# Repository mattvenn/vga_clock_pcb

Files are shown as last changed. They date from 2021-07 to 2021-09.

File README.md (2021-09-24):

Matt Venn's ASIC VGA Clock
==========================

* World's first [certified open source hardware](https://certification.oshwa.org/es000023.html) down to the GDS?
* The ASIC was part of the Google sponsored MPW1
* The ASIC is still in fabrication by Skywater, we expect silicon in September 2021.
* For more details about the implementation, see [VGA ASIC Clock](https://www.zerotoasiccourse.com/post/vga_clock/). 
* RTL: https://github.com/mattvenn/vga-clock
* Application details: https://efabless.com/projects/14

# PCB

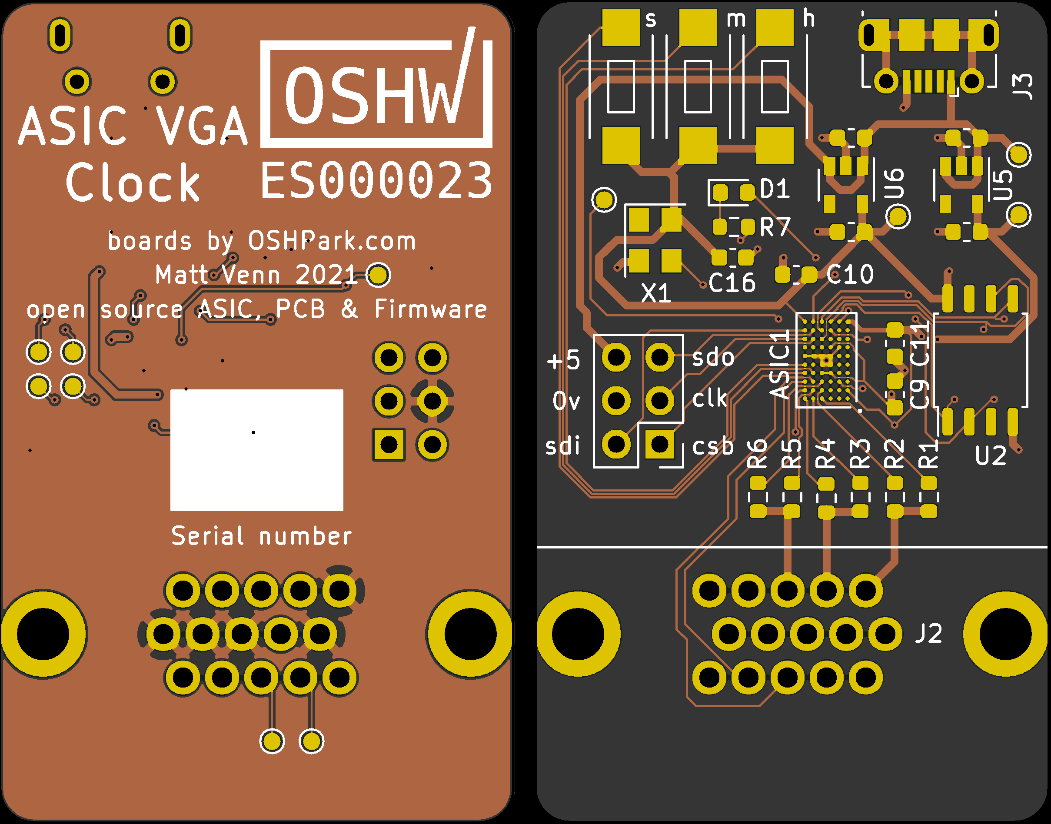
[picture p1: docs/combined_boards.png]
boards


This PCB provides all the necessary components to make a functional clock:

 * Pads for mounting the ASIC
 * Decoupling
 * Voltage regulators for core (1.8) and IO (3.3)
 * Crystal oscillator
 * SOIC-8 footprint for dual SPI flash for the configuration firmware
 * 2x6 1.27mm header with housekeeping SPI, UART and 5V - the minimum connection needed for power and debug
 * [PDF Schematic](rev0.1/carrier.pdf)

# Setup

## Firmware

Needs to active project 2. See https://github.com/mattvenn/caravel-mph/blob/release/verilog/dv/caravel/user_proj_example/vga-clock/vga_clock.c for the simulation test.
Will need PLL setup to work on the ASIC.

## Flashing

For flashing, see https://github.com/efabless/ravenna/blob/master/firmware/blink/Makefile as a starting point. ravenna_hkspi.py may need some tweaks to work with Caravel.

The [SPI interface can be used to put the ASIC into 'passthrough' mode](https://caravel-harness.readthedocs.io/en/latest/housekeeping-spi.html#housekeeping-spi-command-words). Then the FLASH can be programmed through this same SPI interface.

See the schematic for the pinout of the SPI interface on the board.

## PLL config

Needs 31.5MHz for VGA signal. As precise as possible for good timekeeping.
Input oscillator is 9MHz.

Using https://github.com/kbeckmann/caravel-pll-calculator

    matt-desktop:2003 [main]: ./caravel_pll.py generate --clkout 31.5 --clkin 9
    PLL Parameters:

    clkin:    9.00 MHz
    clkout:   31.50 MHz
    clkout90: 31.50 MHz

    PLL Feedback Divider: 14
    PLL Output Divider 1: 4
    PLL Output Divider 2: 4

    Register 0x11: 0x24
    Register 0x12: 0x0e

## Pinning

See the instantiation into the user project area here: https://github.com/mattvenn/multi-project-harness/blob/separate-macro/user_project_wrapper.v#L190
See the design repository here: https://github.com/mattvenn/vga-clock/tree/db029c38607c8d27f54b48bd8fd423cae3c4ed3d

    vga_clock proj_2 (
        .clk(proj2_clk),
        .reset_n(proj2_reset),
        .adj_hrs(proj2_io_in[8]),
        .adj_min(proj2_io_in[9]),
        .adj_sec(proj2_io_in[10]),
        .hsync(proj2_io_out[11]),
        .vsync(proj2_io_out[12]),
        .rrggbb(proj2_io_out[18:13])
        );

* rrggbb is mapped to R1, R2, G1, G2, B1, B2
* 500R used for R1, G1, B1
* 1k used for R2, G2, B2

## Power

### User project

* Power is provided to the clock design only by VCCD1 and VSSD1.
* Tim Edwards suggests:
    * keeping VCCD2 and VCCD1, VSSD2 and VSSD1 tied together just to make sure there are no floating power supplies.  
    * connect VDDA1 and VDDA2 to VDDIO, and VSSA1 and VSSA2 to VSSIO to make sure they're not floating.  
For reference, the power ring around the user project area has 4 buses. From outside to inside:  VSSA2, VDDA2, VSSA1, VDDA1, VSSD2, VCCD2, VSSD1, VCCD1.
    * VSSA2 user area 2 ground
    * VDDA2 3.3V user area 2 psu
    * VSSA1 user area 1 ground
    * VDDA1 3.3V user area 1 psu
    * VSSD2 user area 2 digital ground
    * VCCD2 1.8V user area 2 digital psu
    * VSSD1 user area 1 digital ground
    * VCCD1 1.8V user area 1 digital psu

### Management

* VDDIO/VSSIO   power and ground for IO (up to 5v). I'm connecting to 3.3v
* VDDA/VSSA     3.3v PSU for management area
* VCCD/VSSD     1.8v PSU for management area

# BOM

All available from digikey as of 13/7/21

* regulators
    * 1.8v MCP1824T-1802E/OT
    * 3.3v MIC5504-3.3YM5-TR
* flash: W25Q32JVSSIQ-TR
* oscillator: SIT8008AI-23-33S-9.000000 
* VGA connector: L77HDE15SD1CH4F
* USB connector: 1050170001
* buttons: PTS636 SM25J SMTR LFS

# Errata

## v0.1

* Initial footprint for ASIC was flipped. 
* All other components were tested and worked as expected.

## v0.2

* TBD

# Resources

* PCB forked from https://github.com/samlittlewood/caravel_carrier
* Caravel datasheet: https://caravel-harness.readthedocs.io/en/latest
* Logo created at: http://oshwmark.capablerobot.com/
* PCBs sponsored by https://OSHPark.com

# License

* The PCB is licensed under the [MIT License](LICENSE)
* The ASIC is licensed under the [Apache2 License](https://github.com/mattvenn/vga-clock/blob/master/LICENSE-2.0.txt)
* The documentation is licensed under the [CC0 License](CC0_license)

# Open Source Hardware

This board is an OSHWA approved design: [ES000023](https://certification.oshwa.org/es000023.html)

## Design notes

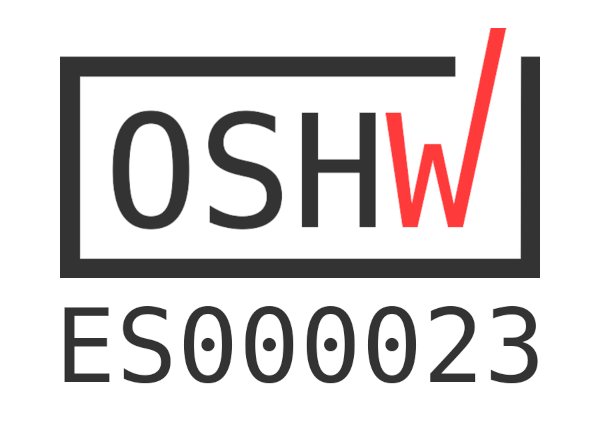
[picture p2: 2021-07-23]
docs/OSHW_mark_ES000023.png

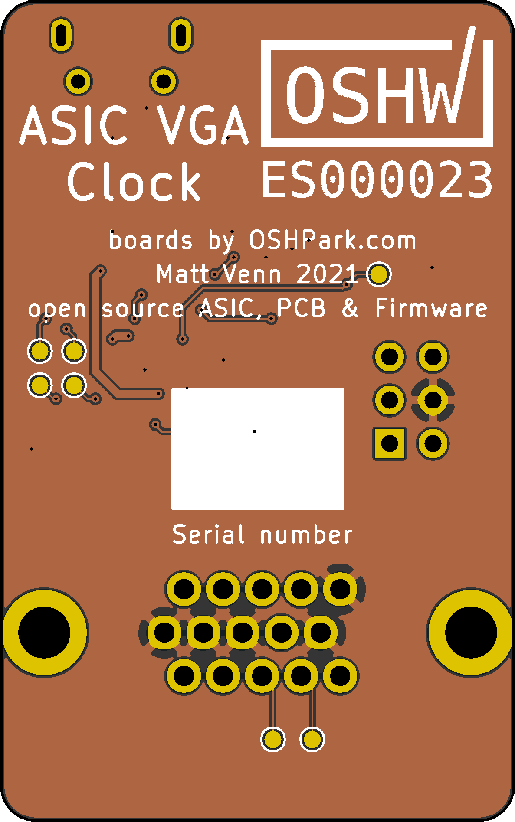
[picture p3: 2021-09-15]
docs/back.png

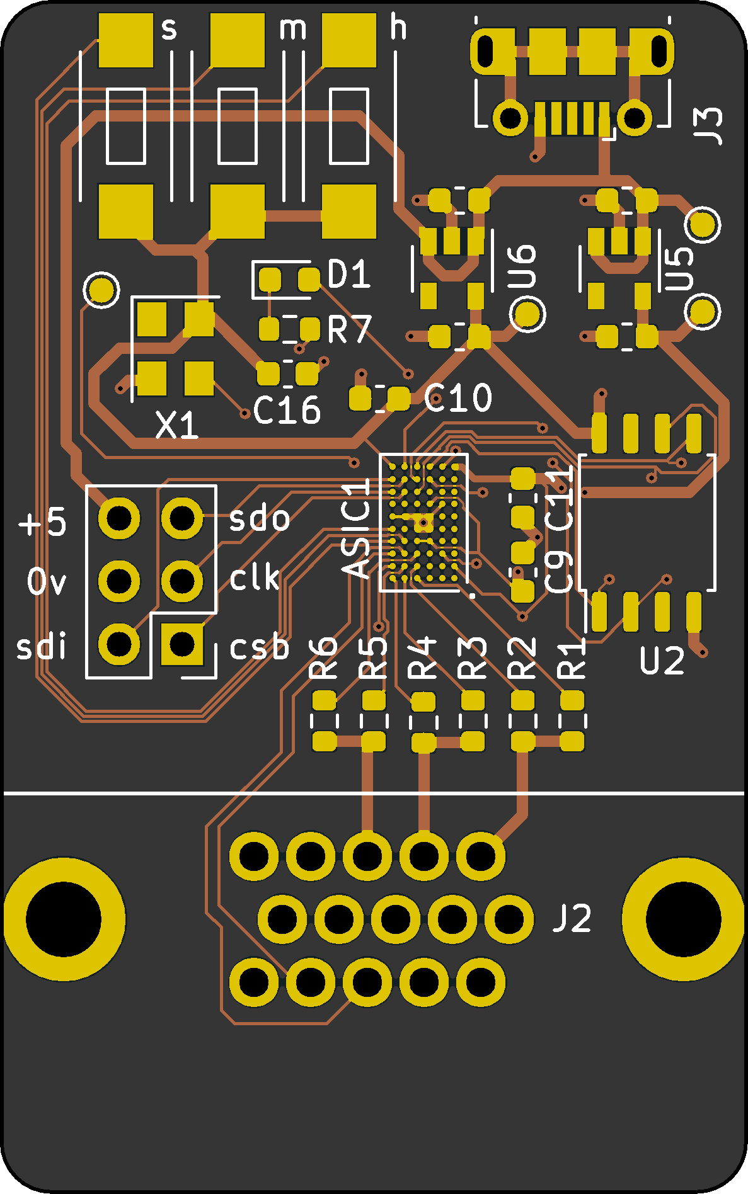
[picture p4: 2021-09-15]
docs/front.png

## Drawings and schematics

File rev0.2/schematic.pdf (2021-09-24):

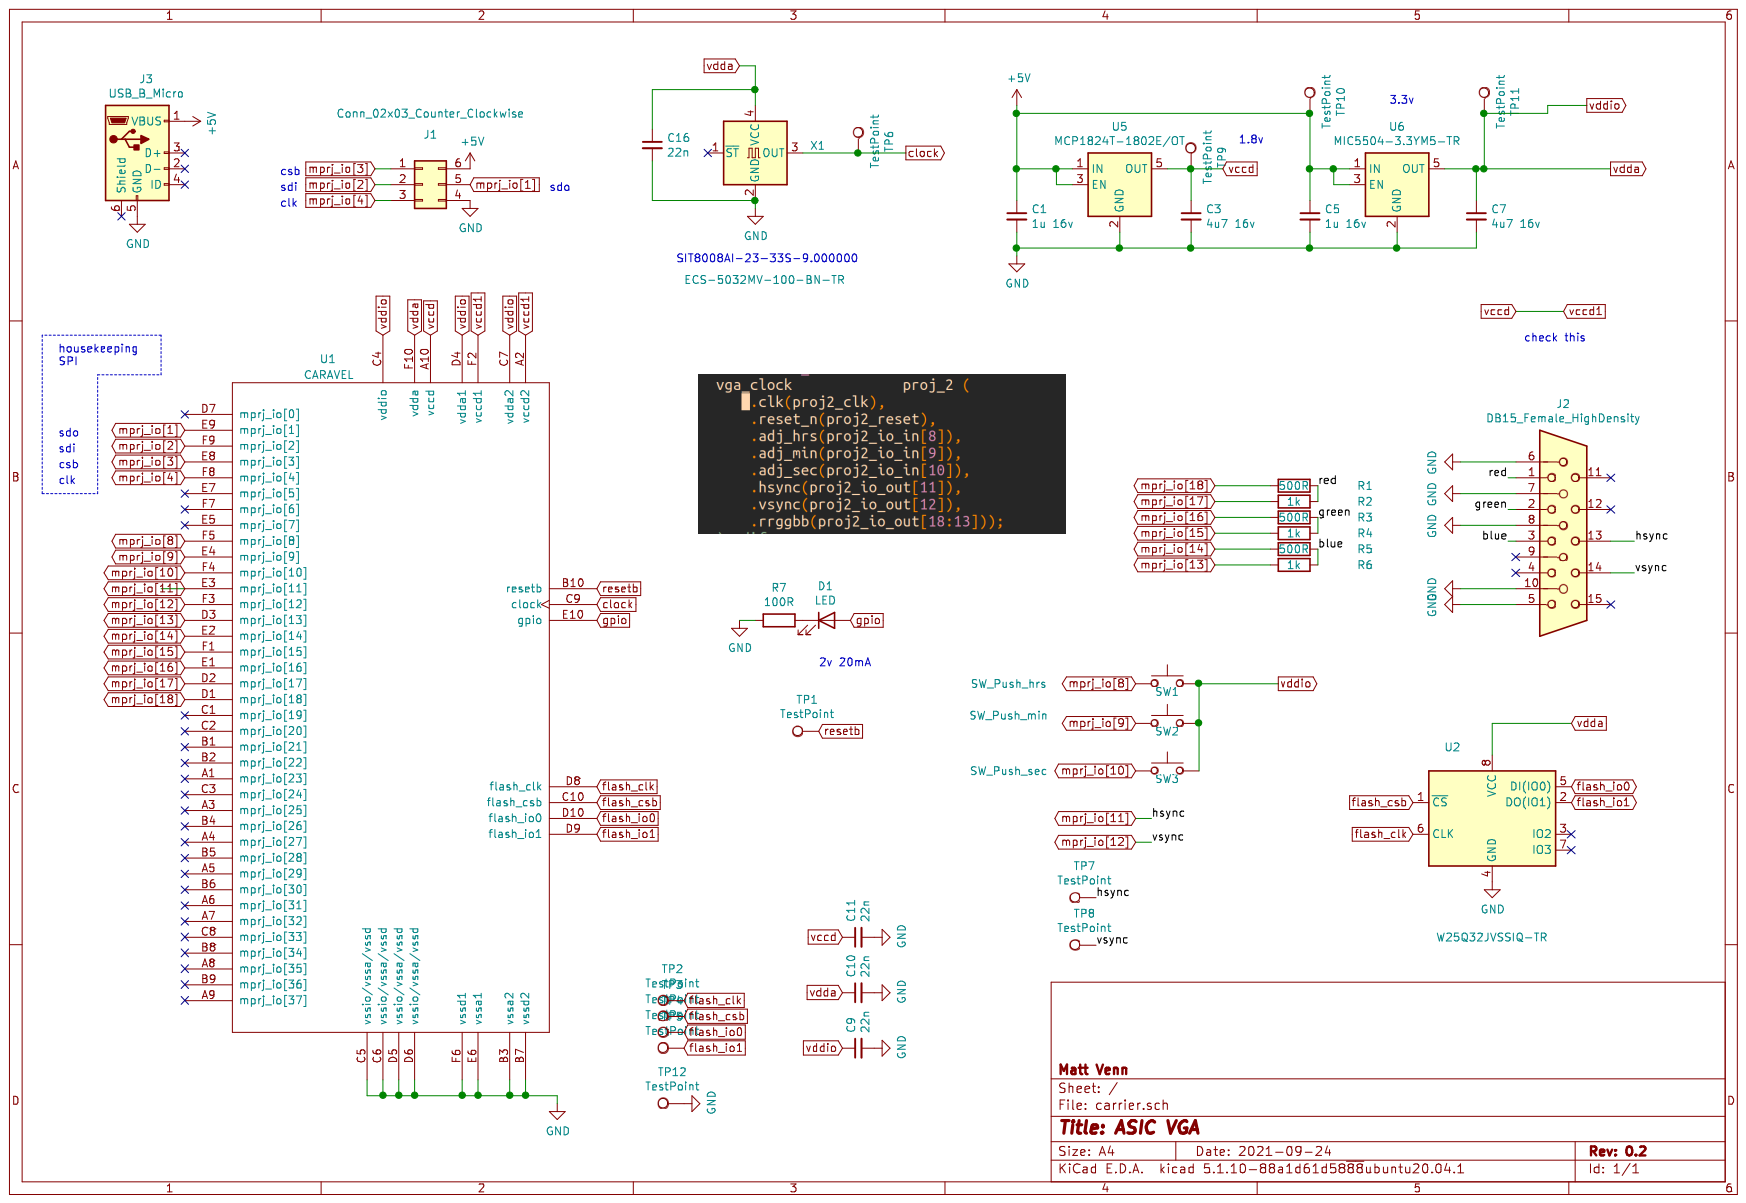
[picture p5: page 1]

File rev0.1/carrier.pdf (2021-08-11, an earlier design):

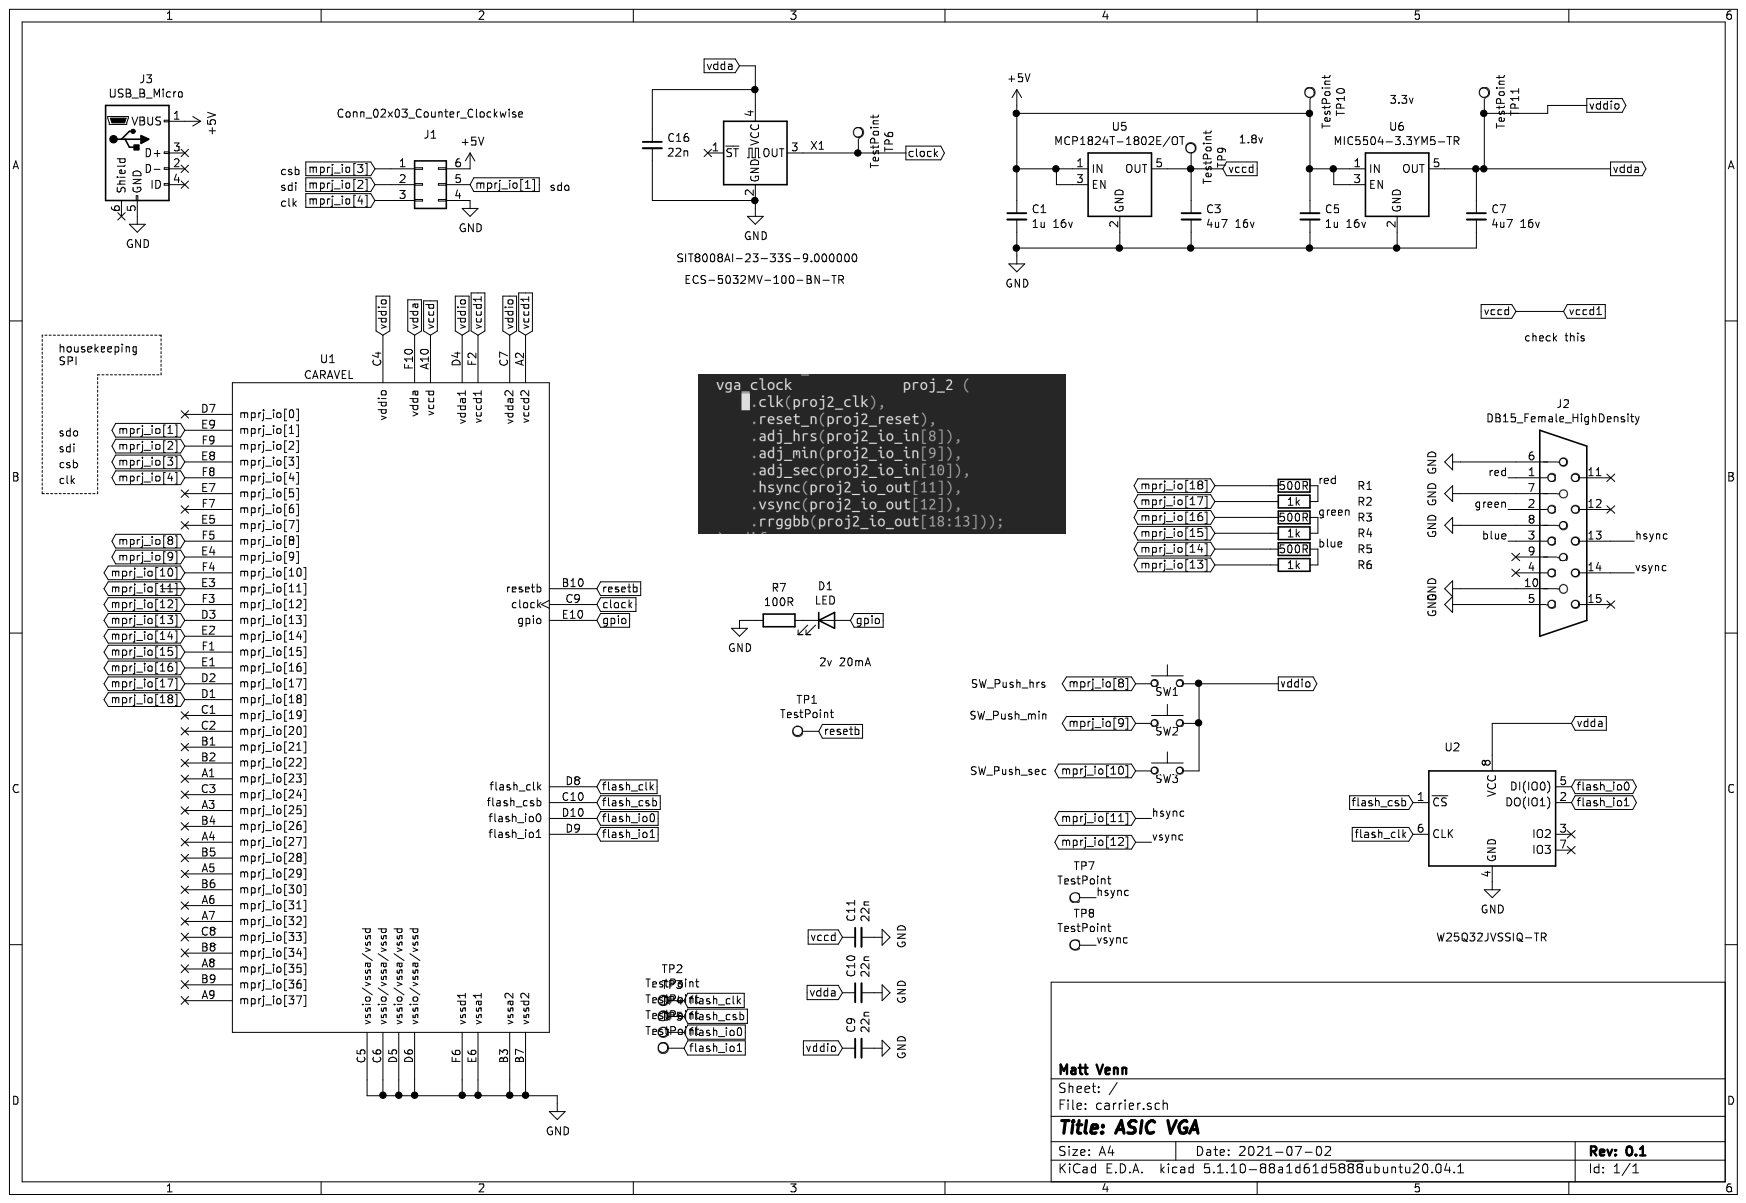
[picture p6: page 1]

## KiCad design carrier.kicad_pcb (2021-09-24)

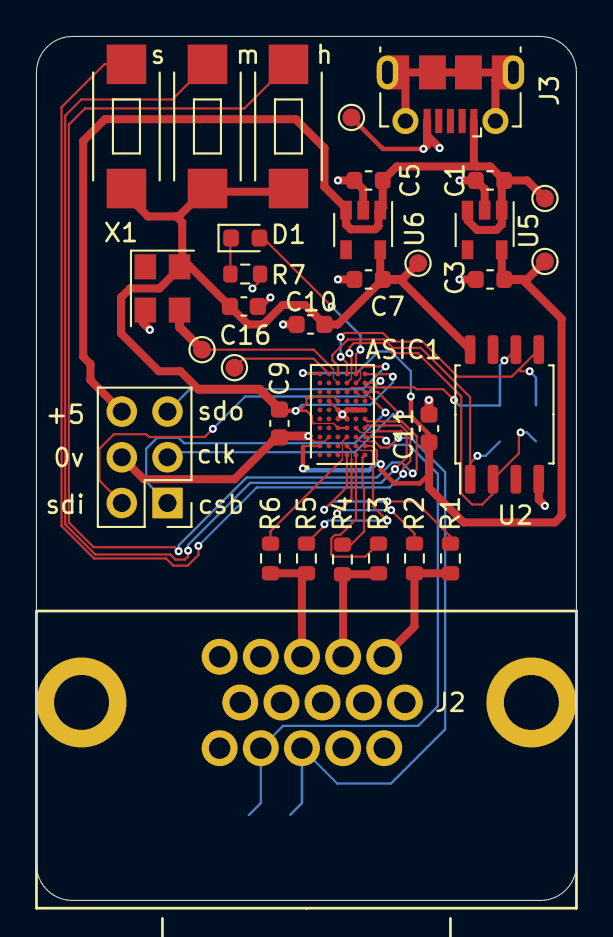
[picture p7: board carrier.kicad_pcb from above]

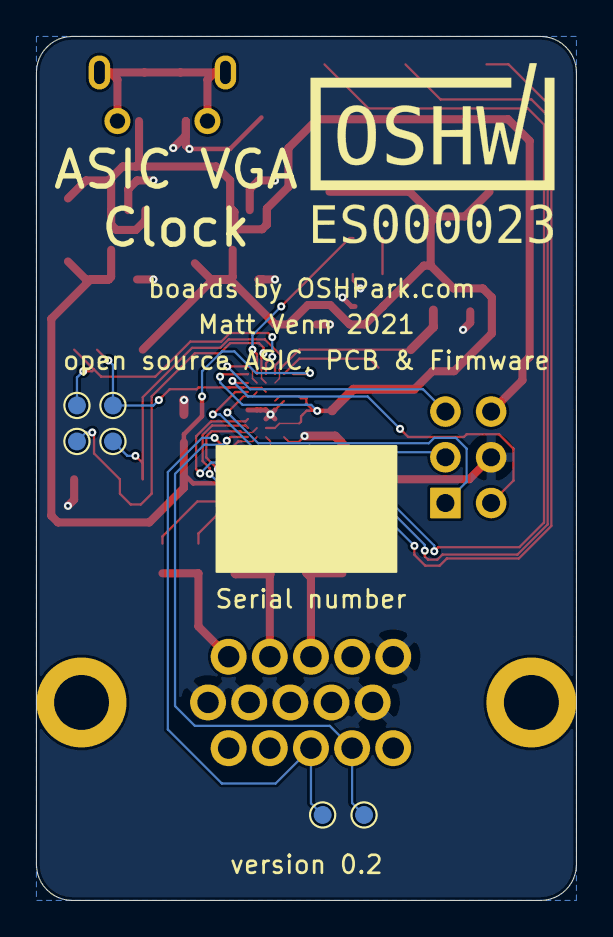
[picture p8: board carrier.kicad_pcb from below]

Board: 2 copper layers, 30.0 x 48.0 mm, 39 parts (6 on the bottom side), 30 nets.

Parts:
ASIC1: CARAVEL; WLCSP-60_P0.5mm
C1, C5: 1u 16v; C_0603_1608Metric
C3, C7: 4u7 16v; C_0603_1608Metric
C9, C10, C11, C16: 22n; C_0603_1608Metric
D1: LED; LED_0603_1608Metric
J1: Conn_02x03_Counter_Clockwise; PinHeader_2x03_P2.54mm_Vertical
J2: DB15_Female_HighDensity; db15
J3: USB_B_Micro; USB_Micro-B_Molex-105017-0001
R1, R3, R5: 500R; R_0603_1608Metric
R2, R4, R6: 1k; R_0603_1608Metric
R7: 100R; R_0603_1608Metric
SW1: SW_Push_hrs; pts636
SW2: SW_Push_min; pts636
SW3: SW_Push_sec; pts636
TP1, TP2, TP3, TP4, TP5, TP6, TP7, TP8, TP9, TP10, TP11, TP12: TestPoint; TestPoint_Pad_D1.0mm
U2: W25Q32JVSSIQ-TR; SOIC-8_5.23x5.23mm_P1.27mm
U5: MCP1824T-1802E/OT; SOT-23-5
U6: MIC5504-3.3YM5-TR; SOT-23-5
X1: ECS-5032MV-100-BN-TR; Oscillator_SMD_SeikoEpson_SG8002CE-4Pin_3.2x2.5mm

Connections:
+5V: C1.1, C5.1, J1.6, J3.1, TP10.1, U5.1, U5.3, U6.1, U6.3
/blue: J2.3, R5.1, R6.1
/green: J2.2, R3.1, R4.1
/red: J2.1, R1.1, R2.1
GND: ASIC1.B3, ASIC1.B7, ASIC1.C5, ASIC1.C6, ASIC1.D5, ASIC1.D6, ASIC1.E6, ASIC1.F6, C1.2, C3.2, C5.2, C7.2, C9.2, C10.2, C11.2, C16.2, J1.4, J2.5, J2.6, J2.7, J2.8, J2.10, J3.5, R7.2, TP12.1, U2.4, U5.2, U6.2, X1.2
unnamed: D1.1, R7.1
clock: ASIC1.C9, TP6.1, X1.3
flash_clk: ASIC1.D8, TP2.1, U2.6
flash_csb: ASIC1.C10, TP3.1, U2.1
flash_io0: ASIC1.D10, TP4.1, U2.5
flash_io1: ASIC1.D9, TP5.1, U2.2
gpio: ASIC1.E10, D1.2
mprj_io[1]: ASIC1.E9, J1.5
mprj_io[2]: ASIC1.F9, J1.2
mprj_io[3]: ASIC1.E8, J1.1
mprj_io[4]: ASIC1.F8, J1.3
mprj_io[8]: ASIC1.F5, SW1.1
mprj_io[9]: ASIC1.E4, SW2.1
mprj_io[10]: ASIC1.F4, SW3.1
mprj_io[11]: ASIC1.E3, J2.13, TP7.1
mprj_io[12]: ASIC1.F3, J2.14, TP8.1
mprj_io[13]: ASIC1.D3, R6.2
mprj_io[14]: ASIC1.E2, R5.2
mprj_io[15]: ASIC1.F1, R4.2
mprj_io[16]: ASIC1.E1, R3.2
mprj_io[17]: ASIC1.D2, R2.2
mprj_io[18]: ASIC1.D1, R1.2
resetb: ASIC1.B10, TP1.1
vccd: ASIC1.A2, ASIC1.A10, ASIC1.F2, C3.1, C11.1, TP9.1, U5.5
vdda: ASIC1.C4, ASIC1.C7, ASIC1.D4, ASIC1.F10, C7.1, C9.1, C10.1, C16.1, SW1.2, SW2.2, SW3.2, TP11.1, U2.8, U6.5, X1.4

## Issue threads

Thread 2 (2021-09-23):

ASIC footprint is flipped

mattvenn, 2021-09-23:

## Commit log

2020-11-21 Add kicad files.
    [carrier-B_Cu.gbr, carrier-B_Mask.gbr, carrier-B_Paste.gbr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]
2020-11-23 Tidy up and ground pours.
    [carrier.kicad_pcb, carrier.sch]
2020-11-23 Updated plots.
    [carrier-B_Cu.gbr, carrier-B_Mask.gbr, carrier-B_Paste.gbr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]
2020-11-23 Tidy up regulators.
    [carrier.kicad_pcb]
2020-11-23 Flipped to have regulators at top, makes pin/io number a better match.
    [carrier-B_Cu.gbr, carrier-B_Mask.gbr, carrier-B_Paste.gbr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]
2020-11-23 Tidy up power routing.
    [carrier-B_Cu.gbr, carrier-B_Mask.gbr, carrier-B_Paste.gbr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]
2020-11-23 Tidy up oscillator.
    [carrier-B_Cu.gbr, carrier-B_Mask.gbr, carrier-B_Paste.gbr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]
2020-11-23 Solder mask clearance.
    [carrier-B_Cu.gbr, carrier-B_Mask.gbr, carrier-B_Paste.gbr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]
2020-11-24 Use 1.27mm header.
    [carrier-B_Cu.gbr, carrier-B_Mask.gbr, carrier-B_Paste.gbr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]
2020-11-27 Clean up clearances.
    [carrier-B_Cu.gbr, carrier-B_Mask.gbr, carrier-B_Paste.gbr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]
2020-12-18 Use 5mil for inner layers.
    [carrier.kicad_pcb]
2020-12-18 Correct directions on global labels.
    [carrier.kicad_pcb, carrier.sch]
2020-12-20 Update gerbers & pdf.
    [carrier-B_Cu.gbr, carrier-B_Mask.gbr, carrier-B_Paste.gbr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]
2020-12-23 Make wlcsp escape 3mil/3mil.
    [carrier.kicad_pcb]
2020-12-23 Made rest of board 4mil/4mil.
    [carrier.kicad_pcb]
2020-12-23 New output files.
    [carrier-B_Cu.gbr, carrier-B_Mask.gbr, carrier-B_Paste.gbr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]
2021-04-17 Update README.md
    make it more discoverable with searches. I tried all variants of pcb, shuttle, asic, caravel, efabless and couldn't find it!
2021-07-06 updating for vga clock
    [carrier-B_Cu.gbr, carrier-B_Mask.gbr, carrier-B_Paste.gbr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]
2021-07-06 pdf of schematic
2021-07-06 updated pcb
    [carrier.kicad_pcb, carrier.sch]
2021-07-06 docs and license. fix db15 fp, add oshw logo
    [carrier.kicad_pcb, carrier.sch]
2021-07-06 routing and silk improvements, added an led to GPIO
    [carrier.kicad_pcb, carrier.sch]
2021-07-06 DAC ladder updated
    [carrier.sch]
2021-07-06 continue to tweak layout
    [carrier.kicad_pcb]
2021-07-13 all BOM parts found on digikey, button footprint
    [carrier.kicad_pcb, carrier.sch]
2021-07-23 updated board with OSHW mark
    [carrier.kicad_pcb]
2021-07-27 update boards from Drews render
2021-07-28 update gerbers
    [carrier-B_Cu.gbr, carrier-B_Mask.gbr, carrier-B_Paste.gbr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]
2021-07-29 switch to 3.2x2.5 9mhz oscillator, only use 3/3 right under ASIC
    [carrier-B_Cu.gbr, carrier-B_Mask.gbr, carrier-B_Paste.gbr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]
2021-07-29 changed programming header to 2x3
    [carrier-B_Cu.gbr, carrier-B_Mask.gbr, carrier-B_Paste.gbr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]
2021-08-11 test points, added managment area psu notes to readme
    [carrier-B_Cu.gbr, carrier-B_Mask.gbr, carrier-B_Paste.gbr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]
2021-08-11 missing oshwa logo
    [carrier-B_Cu.gbr, carrier-B_Mask.gbr, carrier-B_Paste.gbr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]
2021-09-23 flip footprint
2021-09-23 updated to correct asic fp
    [carrier.kicad_pcb]
2021-09-24 rev0.2 gerber
    [carrier-B_Cu.gbr, carrier-B_Mask.gbr, carrier-B_Paste.gbr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]
2021-09-24 fix flipped asic fp, updated to v0.2, added ground testpad, added silk version, notes on testing the regs and clock
    [carrier.kicad_pcb, carrier.sch]
